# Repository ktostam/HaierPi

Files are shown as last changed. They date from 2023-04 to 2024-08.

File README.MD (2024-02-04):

# HaierPi



This project allows you to control HAIER heat pumps. 
## Tested with
1. AU082FYCRA(HW)
2. AU162FYCRA(HW)

All tests were performed on a pump with an additional ATW-a01 unit

However, it should work with all pumps that feature the YR-e27 remote control

If you have any question you can find me on discord:

[Discord Banner 2
](https://discord.gg/dVXmAfWt3P)

## Patrons
- Radek Michalowski

## Contributors
- @kocur on discord channel
- @Radek on discord channel

## Donation
If you like My work and want to support my work, you can:

[](https://patronite.pl/haierpi)

[](https://www.buymeacoffee.com/jacekbrzozZ)

Or if you from Poland:

[](https://buycoffee.to/jacekbrzozz)

## HARDWARE

## PCB
PCB layout is designed for both RaspberryPi zeroW and NanoPi neo 1.4.

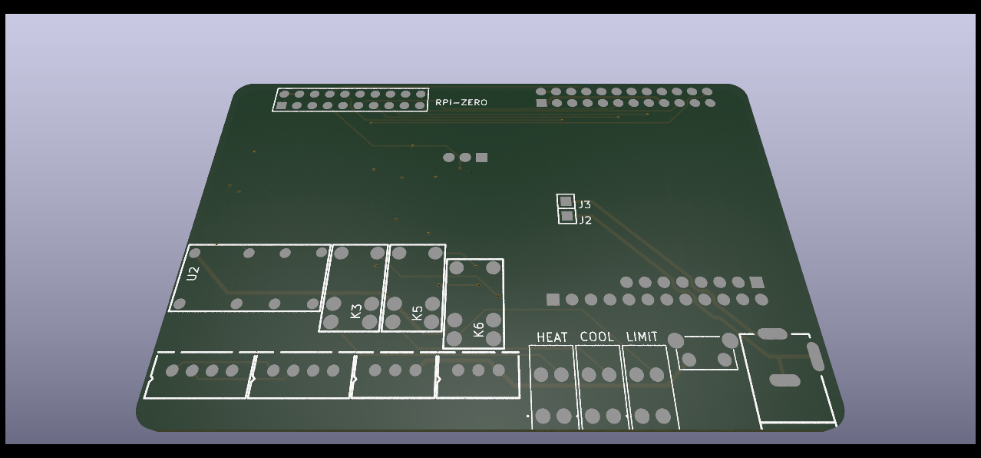
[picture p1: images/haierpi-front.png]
Front


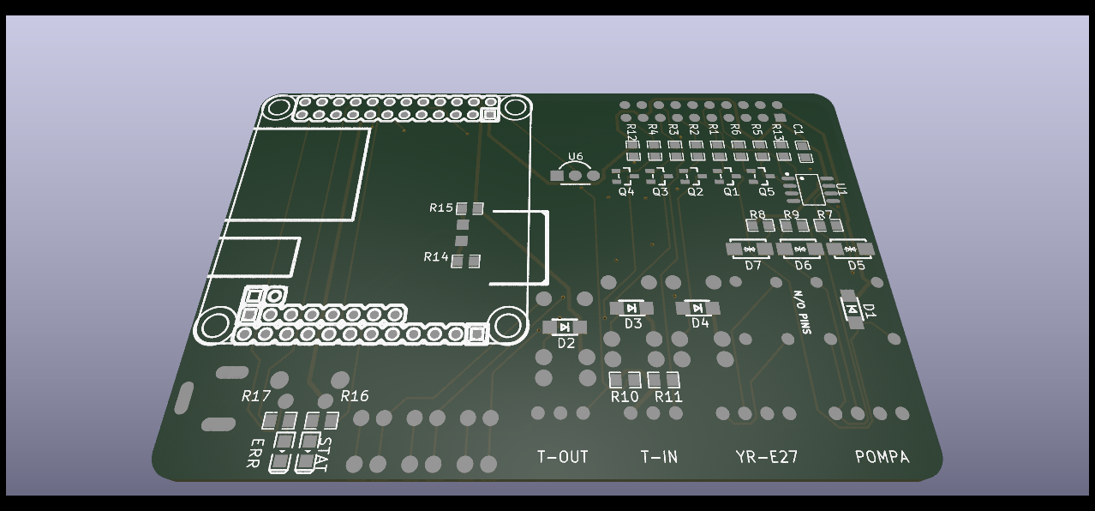
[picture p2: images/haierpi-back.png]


### PCB 1.1
The revised version of the PCB (1.1) no longer has mislabeling. In addition, one of the leds and the button is now also connected to the RPi.

In the future, HaierPi will support only NanoPi

### Component List

| Symbol | Value | Footprint |
|---|---|---|
| J1 | ADC-002 | ADC-002 |
| H3-H4 | JST XH 3 | JST-XH-TH-3-2.5  |
| POMPA,YR-E27  | JST XH 4 | JST-XH-TH-4-2.5  |
| CON1-CON3 | DG308-2.54/2 | |
| R1-R4 | 1K | SMD 0805 |
| R5-R8,R10-R12 | 4.7K | SMD 0805 |
| R9 | 120 | SMD 0805 |
| R13-R15 | 0 | SMD 0805 |
| R16-R17 | 330 | SMD 0805 |
| C1 | 104 | SMD 0805 |
| LED1 | RED | SMD 0805 |
| LED2 | GREEN | SMD 0805 |
| D1-D4 | 1N4007W | SOD-123 |
| D5-D7 | SMAJ12CA | DO214AC |
| REL1 | N4078-2C-5V-0.2W | N4078-2C-5V-0.2W |
| REL2-REL4 | HFD23-005-1ZS | HFD23-005-1ZS |
| U1 | MAX3485 | SOP-8 |

### ERRATA
In the first batch of PCB's was error
PCB descriptions of R1 and R2 are swapped places, so if you have that PCB,
you need to solder 1K resistor on R6 and 4.7 on R1

### Disclaimer
- R9 is RS485 EOL resistor. For this application don't solder it.
- Resistor R14-R15 is for choosing what type to board you want to connect (Raspberrypi/NanoPi Neo). For NanoPi, 
solder 0 Ohm resistor for powering NanoPi via GPIO. `If you connect Raspberry Pi don't solder it`, because powering RPi 
from GPIO bypasses builtin protections. I will be work but its not safe. If you connecting Raspberry Pi zero W, connect
`J2`(GND) to `PP6` pad, and `J3`(+5V) to `PP1` pad. 

### Raspberry Pi
if you want to use the script on the raspberry pi, you need to add the following settings to `config.txt`:

```shell
dtoverlay=w1-gpio,gpiopin=4
dtoverlay=pi3-disable-bt
enable_uart=1
```
Be aware that this settings will disable bluetooth. but we need use UART0

### Nano Pi neo 1.4
Script is also tested on NanoPi neo 1.4. For now no change is required, but in future, when support for hardware
temperature sensor will be added, we need to remap some GPIO pins. Further information will be added later.

### Other platform
script needs a relay to control the data flow in order to function properly, so best choice is some sort of SBC.
At the moment there are no plans to add support for other SBCs, but maybe in future I will add support for relays controlled by Home Assistant, 
so script may running on any platform, and only need a RS485 connection.

## Wiki
Now the documentation is on the wiki (only in polish for now)  [wiki](https://wiki.haos.it)

## Translation
- en
- pl
### if you want to help create a translation into another language write me an email or on the discord channel

## Version
### 1.37
- Add charts with some parameters
- DHW without limit function run in turbo mode
- Add estimated daily energy consumption, separate for central heating and domestic hot water

### 1.35
- Add MQTT Discovery (by Radek)
- Add more option for heatingcurve
- Add Anti ON-OFF function
- Add DHW without limit function
- Add Parameters page
- Add Temperature Charts
- Minor fixes

### 1.32
- Add parameters
- Add scheduler for CH and DHW
- Add translation to polish
- Now changes to settings do not require a restart of the service
- New update script, from now all new update dont need to manualy add option in config.ini.
- Minor fixes

### 1.31
- Add function for automatic/manual control of frequency limit relay
- Add function for automatic/manual control of mode quiet/eco/turbo
- IMPORTANT: new option added in config.ini. If you're updating
  from previous version you need to add options: `log_leve = ERROR` in  `[DEFAULT]` block in `config.ini`
  `flimit = manual`, `flimit_temp = 10`, `presetautochange = manual`,`presetquiet = 10`,`presetturbo = -10` in `[SETTINGS]` block in `config.ini`
- minor fixes
### 1.30
- Add possibility to change heating curve parameters via settings page.
- IMPORTANT: new option added in config.ini. If you're updating
  from previous version you need to add option `hcslope = 0.7`, `hcpshift = 1` and `hcamp = 1` in `[SETTINGS]` block in `config.ini`
- Add chart with heating curve visualisation.
- minor fixes

### 1.26
- IMPORTANT: new option added in config.ini. If you're updating
  from previous version you need to add option `firstrun = 0` in `[DEFAULT]` block in `config.ini`
- Setting page is kinda ready. (unfortunetly you need to manualy restart HaierPi service after saving change for now)
- Added new service for display HaierPi logs via web, for better debugging. Now you don't need to login via ssh
- Now script can talk with home assistant via MQTT (for now there is no mqtt autodiscovery, so you need to add yaml configuration manualy).
- Updates only send via mqtt if something is changes, not as before - everything every 10 seconds
- TODO: add option somewhere to restart HaierPi service. (e.g. after config.ini changed via web)
- Minor fixes

### 1.18
- Add ds18b20 sensor support as outside temp sensor.
- Fixed error handling that could cause sysexit.
- Adding new update mechanism
 need to add new option in `config.ini`:
```shell
    release=master
```
- Minor fixes
### 1.1
In this release I change library to control GPIO, Iam not using RPi.GPIO anymore, there is some issue with RPi.GPIO replacement for Nano Pi, so I decided to control GPIO via system /sys/class/gpio/. This is independent from used SBC,

in `config.ini` there is new configuration for PIN:
```shell
[GPIO]
modbus=17 #17 for raspberrypi, 0 for nanopi neo
freqlimit=27 #27 for raspberrypi, 2 for nanopi neo
heatdemand=22 #22 for raspberrypi, 3 for nanopi neo
cooldemand=10 #10 for raspberrypi, 64 for nanopi neo
```

### 1.0

First release. for now, the following features are available:

- Show pump parameters
- Set DHW temperature
- Set Central Heating Temperature 
- Heating water temperature is calculated according to the heating curve
- Online update

#### disclaimer:
In this release inside and outside temperature must be provided by Home Assistant sensors.
For future release hardware sensor will be supported (ds18b20 for outside and DHT22 for inside temperature).

In this release, MQTT support is not finished

## LICENSE
 GNU Affero General Public License v3 [©Jacek Brzozowski](https://github.com/ktostam/HaierPi)

In this project I'am using:
[open-meteo](https://open-meteo.com/) - CC BY 4.0

[jquery-schedule](https://github.com/Yehzuna/jquery-schedule) - MIT License

[sweetalert2](https://github.com/sweetalert2/sweetalert2) - MIT License

[bootstrap](https://github.com/twbs/bootstrap) - MIT License

[jquery](https://github.com/jquery/jquery) - MIT License

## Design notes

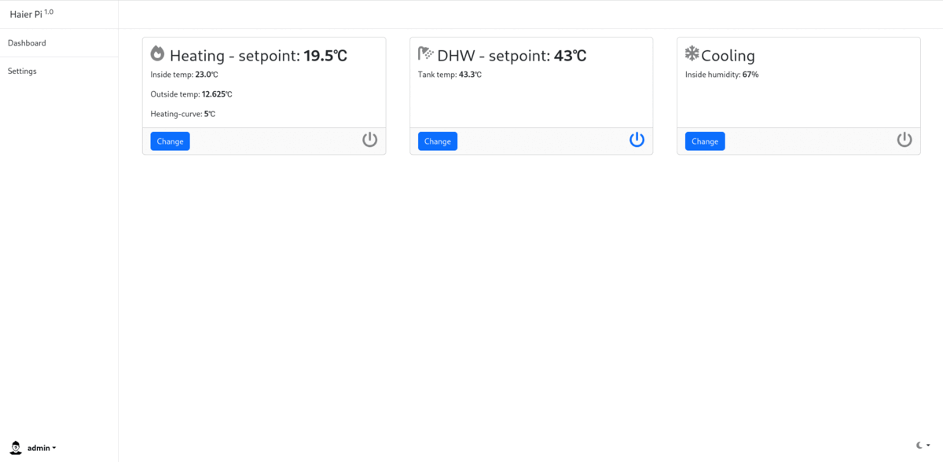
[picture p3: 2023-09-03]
images/screenshot.gif

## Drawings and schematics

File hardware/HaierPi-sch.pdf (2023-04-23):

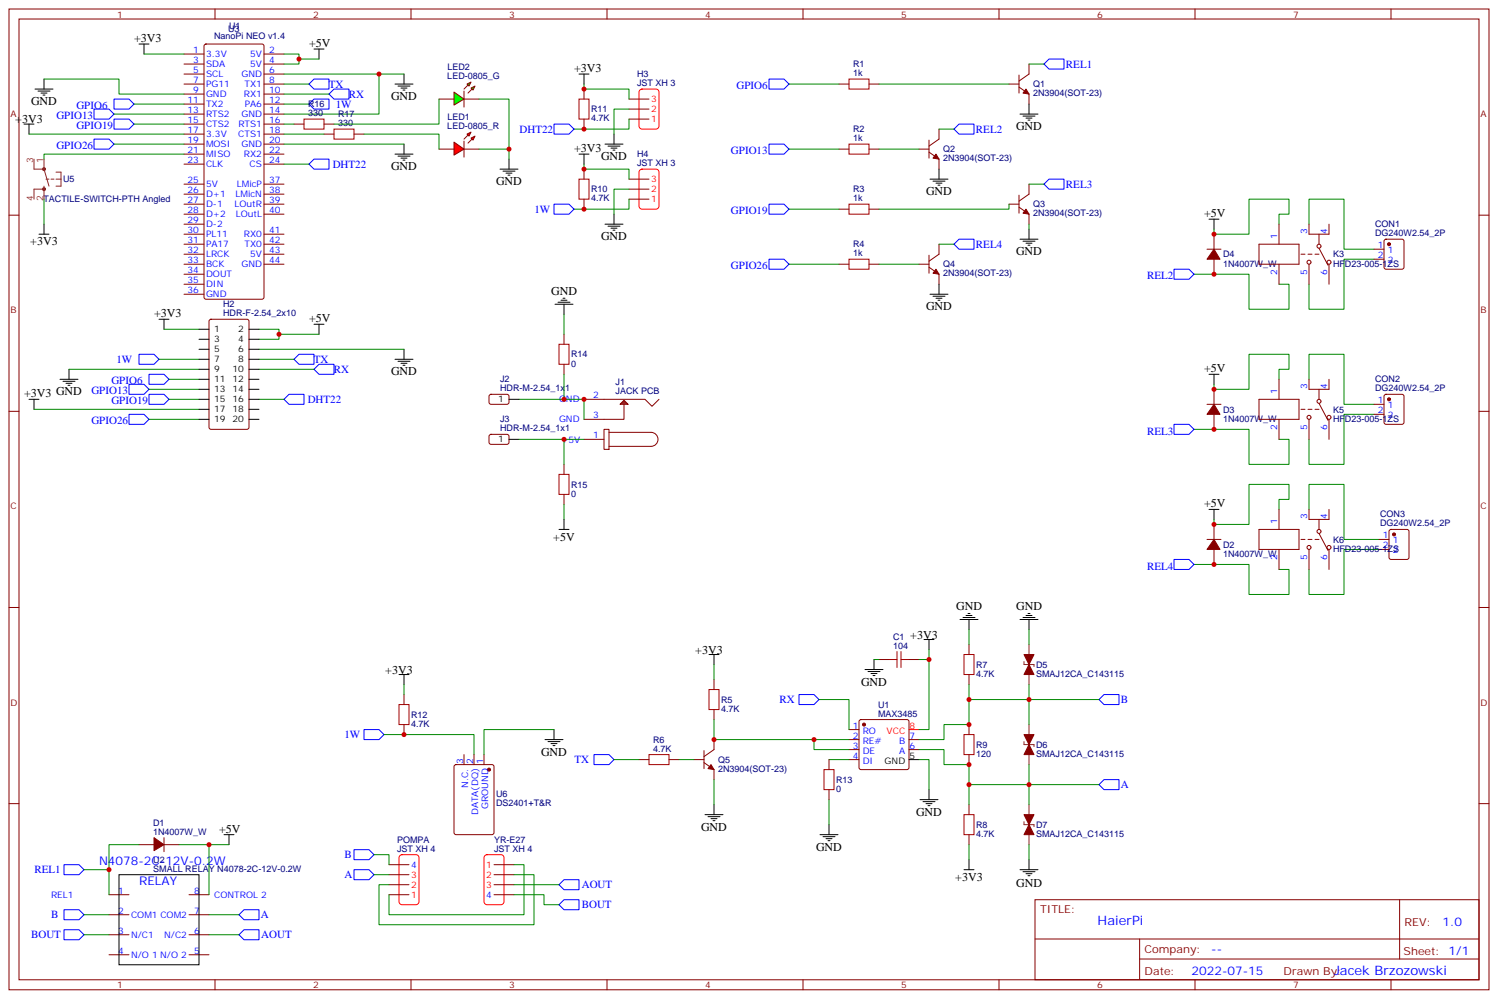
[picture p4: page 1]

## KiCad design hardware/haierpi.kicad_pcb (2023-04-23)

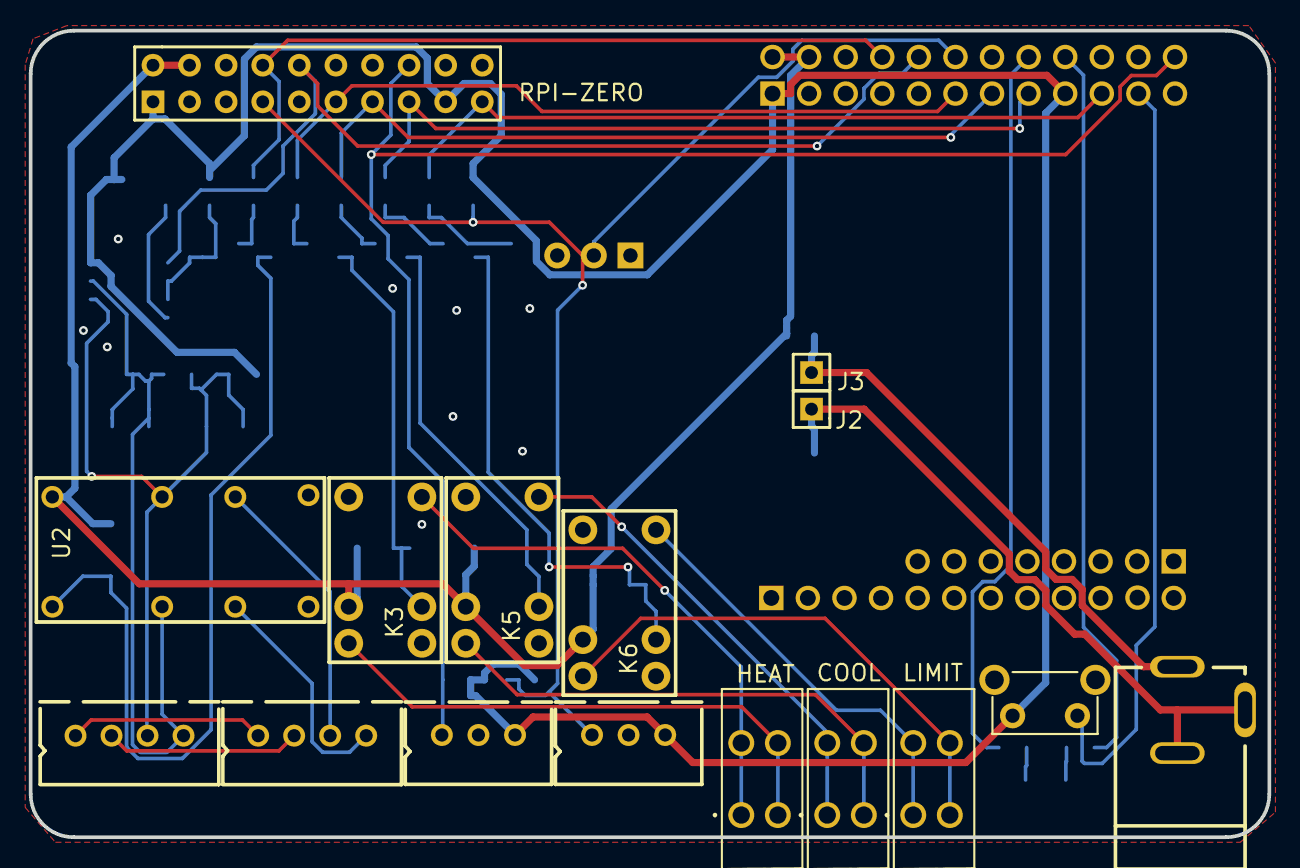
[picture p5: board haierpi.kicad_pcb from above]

Board: 2 copper layers, 86.0 x 56.0 mm, 51 parts (0 on the bottom side), 41 nets.

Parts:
C1: 104; C0805
COOL: DG240W2.54_2P; 2X2P_2.54X5
D1, D2, D3, D4: 1N4007W_W; SOD-123_L2.8-W1.8-LS3.7-RD
D5, D6, D7: SMAJ12CA_C143115; SMA_L4.4-W2.6-LS5.0-BI
ERR: LED-0805_R; LED0805_RED
HEAT: DG240W2.54_2P; 2X2P_2.54X5
J1: JACK PCB; ADC-002
J2, J3: HDR-M-2.54_1x1; HDR-M-2.54_1X1
K3, K5, K6: HFD23-005-1ZS; RELAY-TH_HFD23-005-1ZS
LIMIT: DG240W2.54_2P; 2X2P_2.54X5
POMPA: JST XH 4; JST-XH-TH-4-2.5
Q1, Q2, Q3, Q4, Q5: 2N3904(SOT-23); SOT-23-3_L2.9-W1.3-P1.90-LS2.4-TR
R1, R2, R3, R4: 1k; R0805
R5, R6, R7, R8, R10, R11, R12: 4.7K; R0805
R9: 120; R0805
R13, R14, R15: 0; R0805
R16, R17: 330; R0805
RPI-ZERO: HDR-F-2.54_2x10; HDR-F-2.54_2X10
STAT: LED-0805_G; LED0805_GREEN
T-IN: JST XH 3; JST-XH-TH-3-2.54
T-OUT: JST XH 3; JST-XH-TH-3-2.54
U1: MAX3485; SOP-8_L4.9-W3.9-P1.27-LS6.0-BL-1
U2: N/O PINS; SMALL N4078 DUAL COMS RELAY
U3: a; NANOPI_NEO_V1.4
U5: TACTILE-SWITCH-PTH Angled; SW_TACTILE_SPST_ANGLED
U6: DS2401+T&R; TO-92-3_L4.8-W3.7-P2.54-L
YR-E27: JST XH 4; JST-XH-TH-4-2.5

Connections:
1W: R10.1, R12.1, RPI-ZERO.7, T-OUT.1, U3.12, U6.2
+3V3: C1.2, R5.2, R8.1, R10.2, R11.2, R12.2, RPI-ZERO.1, RPI-ZERO.17, T-IN.3, T-OUT.3, U1.8, U3.1, U3.17, U5.2
+5V: D1.1, D2.1, D3.1, D4.1, K3.1, K5.1, K6.1, R15.1, RPI-ZERO.2, RPI-ZERO.4, U2.8, U3.2, U3.4
A: D6.1, D7.2, POMPA.3, R8.2, R9.1, U1.6, U2.7
AOUT: U2.6, YR-E27.3
B: D5.1, D6.2, POMPA.4, R7.1, R9.2, U1.7, U2.2
BOUT: U2.3, YR-E27.4
CON1_1: HEAT.1, K3.3
CON1_2: HEAT.2, K3.5
CON2_1: COOL.1, K5.3
CON2_2: COOL.2, K5.5
CON3_1: K6.3, LIMIT.1
CON3_2: K6.5, LIMIT.2
DHT22: R11.1, RPI-ZERO.16, T-IN.1, U3.24
GND: C1.1, D5.2, D7.1, ERR.2, Q1.1, Q2.1, Q3.1, Q4.1, Q5.1, R7.2, R13.1, R14.2, RPI-ZERO.6, RPI-ZERO.9, STAT.2, T-IN.2, T-OUT.2, U1.5, U3.6, U3.9, U3.14, U3.20, U6.1
GPIO6: R1.1, RPI-ZERO.11, U3.11
GPIO13: R2.1, RPI-ZERO.13, U3.13
GPIO19: R3.1, RPI-ZERO.15, U3.15
GPIO26: R4.1, RPI-ZERO.19, U3.19
J1_1: J1.1, J3.1, R15.2
J1_2: J1.2, J1.3, J2.1, R14.1
POMPA_1: POMPA.1, YR-E27.1
POMPA_2: POMPA.2, YR-E27.2
Q5_2: Q5.2, R6.1
R1_2: Q1.2, R1.2
R2_2: Q2.2, R2.2
R3_2: Q3.2, R3.2
R4_2: Q4.2, R4.2
R16_2: R16.2, STAT.1
R17_2: ERR.1, R17.2
REL1: D1.2, Q1.3, U2.1
REL2: D4.2, K3.2, Q2.3
REL3: D3.2, K5.2, Q3.3
REL4: D2.2, K6.2, Q4.3
RX: RPI-ZERO.10, U1.1, U3.10
TX: R6.2, RPI-ZERO.8, U3.8
U1_2: Q5.3, R5.1, U1.2, U1.3
U1_4: R13.2, U1.4
U3_16: R16.1, U3.16
U3_18: R17.1, U3.18
U5_1: U3.21, U5.1

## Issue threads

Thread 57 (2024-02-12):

Descriptions and typos

kamilostatek, 2024-02-12:
#: templates/index.html:331
msgid "Heating - setpoint: "
msgstr "Grzanie - zadana: "
in bubble (Inside setpoint temperature  / Temperatura zadana w domu)

#: templates/index.html:334
msgid "Heating-curve: "
msgstr "Krzywa grzewcza: "
in bubble (Temperature calculated from heating curve / Temperatura wyliczona z krzywej grzewczej)

#: templates/index.html:345
msgid "DHW - setpoint: "
msgstr "CWU - zadana: "
in bubble "Setpoint Tank temperature for Domestic Hot Water/ Zadana temperatura zbiornika CWU lub z wodą użytkową"

#: templates/index.html:374
msgid "Compressor Frequency limit: - "
msgstr "Ograniczenie częstotliwości sprężarki: - "
in bubble (Bypass/jumper on CN23 connector / Zworka na złączu CN23)

#: templates/index.html:389
msgid "Frequency limit temp: "
msgstr "Temperatura ograniczenia częstotliwości: "
in bubble (Temperature above which the function will be active / Temperatura powyżej której funkcja będzie aktywna)

#: templates/settings.html:259
msgid "Longitude"
msgstr "Długość geograficzna"

#: templates/settings.html:334
msgid "Heating DHW in Turbo mode and without freq.limit"
msgstr "Grzanie CWU w trybie Turbo i bez zworki ograniczenia częst."

#: templates/settings.html:335
msgid "When heating DHW turn off frequency limit relay and set Turbo mode"
msgstr ""
"Podczas grzania CWU zworka ograniczenia częstotliwości zostanie "
"wyłączona oraz zostanie włączony tryb Turbo"

#: templates/settings.html:385
msgid "Frequency limit"
msgstr "Ograniczenie częstotliwości sprężarki"

#: templates/settings.html:386 templates/settings.html:418
msgid "Automatic or manual frequency limit relay control"
msgstr ""
"Automatyczne lub ręczne sterowanie przekaźnikiem ograniczenia "
"częstotliwości"

New description for option:
Temperature Quiet mode
Temperatura trybu Quiet
W trybie automatycznym - temperatura powyżej której zostanie włączony tryb Quiet
In auto mode - temperature above which Queit mode will be active

Temperature Turbo mode
Temperatura trybu Turbo
W trybie automatycznym - temperatura powyżej której zostanie włączony tryb Turbo
In auto mode - temperature above which Turbo mode will be active

Descriptions for Parametres added in bubbles ?

1 Twi (temperature water input / temperatura wody dolotowej)
2 Two (temperature water output / temperatura wody wylotowej)
3 ΔT (the difference between Two and Twi / różnica pomiędzy Two i Twi)
4 Compressor fact (actual compressor frequency / aktualna częstotliwość sprężarki)
5 Compressor fset (set compressor frequency / zadana częstotliwość sprężarki)
6 Compressor current (prąd sprężarki)
7 Compressor voltage (napięcie sprężarki)
8 Compressor temp. (temperatura sprężarki)
9 Fan 1 speed (prędkość silnika wentylatora 1)
10 Fan 2 speed (prędkość silnika wentylatora 2)
11 Tao (temperatura otoczenia)
12 Td (temperatura strony tłocznej)
13 Ts (temperatura strony ssącej)
14 Thi (temperatura stanu ciekłego czynnika)
15 Tho (temperatura stanu gazowego czynnika)
14 Pd (ciśnienie strony tłocznej)
15 Ps (ciśnienie strony ssącej)
16 Pump (status pompy obiegowej)
17 3-way valve (zawór przełączający)
18 Daily CH kWh (zużycie CO w kWh)
19 Daily DHW kWh (zużycie CWU w kWh)
20 Total daily kWh (zużycie CO + CWU w kwh)

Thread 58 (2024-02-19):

parameter of termination of heating for fixed outside temperature value (high value when heating is not needed anymore)

petec999, 2024-02-19:
Parameter set in UI (e.g.) 17 degrees for outside temperature will cause stop of working of heat pump.
As heating for temperature is not needed when reached.
After temperature will gone down below that value (or another one - e.g. 15 degrees) heating procedure will be started. This solution is applicable in a sort of HPs and prevent power consumption when not needed. Sense of proposed solution to be considered, but it may cause building of a sort of dependencies related with that.

ktostam, 2024-02-19:
I can do something like this, but as an additional option disabled by default. This is an intentional action, if you turn off heating on the remote control and leave "Tank" alone, the 3-way valve will switch permanently to the tank position. This causes the tank to cool down faster (by gravity), unless you have a "heat trap" in the system

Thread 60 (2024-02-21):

adding logging time of archerror

petec999, 2024-02-21:
logging archerrors tagged with date, making it visible in ui

ktostam, 2024-02-21:
It is not that simple. Archerror do not have dates by themselves. the only thing I can do is during the occurrence of some error at a given time, I can save them somewhere along with the date. However, if the error occurs only for a very short moment I may not have time to catch the error, then the "archerror" will not be consistent with the dates it records.

In that case, archerror will display the errors even if they occurred for only a moment, and I will save all that occurred for more than a few seconds.

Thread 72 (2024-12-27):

saving 'heating-curve' value - pumps stops to work when 'inside temp' is unknown

petec999, 2024-12-27:
When value of 'inside temp' is unknown (e.g. it's provided by external sensor, or there's issue with reading value of haierpi sensor), pump stops to work as it cannot calculate 'heating-curve' value'. Proposed solution is to save and store last value and use it in case of such issue.

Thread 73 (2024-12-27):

relay limited frequency of compressor state is not going back after exiting of tank status when heating-curve value is entered manually

petec999, 2024-12-27:
Case: Pump is configured to use limited frequency of compressor using ui, heating-curve value as constant value is entered manually by ui, DHW scheduler is in use. When haierpi is going into 'DHW already off' state, heating curve is not recalculated (as value is entered manually) and pump is not going back into limited frequency of compressor state, TURBO state persists, what is not intended.

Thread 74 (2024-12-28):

Possibility of minor correction of the temperature displayed by the indoor and outdoor temperature sensor

kamilostatek, 2024-12-28:

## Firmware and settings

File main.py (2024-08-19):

from flask_simplelogin import SimpleLogin,is_logged_in,login_required, get_username
from werkzeug.security import check_password_hash, generate_password_hash
from schedule import every, run_pending, get_jobs, clear, cancel_job
from flask import Flask, flash, render_template, request, session, jsonify, redirect, Markup, send_file
from flask_babel import Babel, gettext
from pymodbus.client.sync import ModbusSerialClient
from werkzeug.utils import secure_filename
from w1thermsensor import W1ThermSensor
import collections
import paho.mqtt.client as mqtt
from termcolor import colored
from waitress import serve
from datetime import datetime
import HPi.GPIO as GPIO
import configparser
import subprocess
import threading
import requests
import logging
import PyHaier
import socket
import serial
import signal
import json
import time
import sys
import io

version="1.38"
ip_address=subprocess.run(['hostname', '-I'], check=True, capture_output=True, text=True).stdout.strip()
welcome="\n┌────────────────────────────────────────┐\n│              "+colored("!!!Warning!!!", "red", attrs=['bold','blink'])+colored("             │\n│      This script is experimental       │\n│                                        │\n│ Products are provided strictly \"as-is\" │\n│ without any other warranty or guaranty │\n│              of any kind.              │\n└────────────────────────────────────────┘\n","yellow", attrs=['bold'])
config = configparser.ConfigParser()
config.read('config.ini')
log_level_info = {'DEBUG': logging.DEBUG, 
                    'INFO': logging.INFO,
                    'WARNING': logging.WARNING,
                    'ERROR': logging.ERROR,
                    }

def loadconfig():
    logging.info("Loading new config.ini")
    global loglevel
    loglevel = config['MAIN']['log_level']
    global timeout
    timeout = config['MAIN']['heizfreq']
    global firstrun
    firstrun = config['MAIN']['firstrun']
    global bindaddr
    bindaddr = config['MAIN']['bindaddress']
    global bindport
    bindport = config['MAIN']['bindport']
    global modbusdev
    modbusdev = config['MAIN']['modbusdev']
    global release
    release = config['MAIN']['release']
    global expert_mode
    expert_mode = config['MAIN']['expert_mode']
    global settemp
    settemp = config['SETTINGS']['settemp']
    global slope
    slope = config['SETTINGS']['hcslope']
    global pshift
    pshift = config['SETTINGS']['hcpshift']
    global hcamp
    hcamp = config['SETTINGS']['hcamp']
    global heatingcurve
    heatingcurve = config['SETTINGS']['heatingcurve']
    global insidetemp
    insidetemp = config['SETTINGS']['insidetemp']
    global outsidetemp
    outsidetemp = config['SETTINGS']['outsidetemp']
    global omlat
    omlat = config['SETTINGS']['omlat']
    global omlon
    omlon = config['SETTINGS']['omlon']
    global humidity
    humidity = config['SETTINGS']['humidity']
    global flimit
    flimit = config['SETTINGS']['flimit']
    global flimittemp
    flimittemp = config['SETTINGS']['flimittemp']
    global presetautochange
    presetautochange = config['SETTINGS']['presetautochange']
    global presetquiet
    presetquiet = config['SETTINGS']['presetquiet']
    global presetturbo
    presetturbo = config['SETTINGS']['presetturbo']
    global antionoff
    antionoff = config['SETTINGS']['antionoff']
    global antionoffdelta
    antionoffdelta = config['SETTINGS']['antionoffdelta']
    global chscheduler
    chscheduler = config['SETTINGS']['chscheduler']
    global dhwscheduler
    dhwscheduler = config['SETTINGS']['dhwscheduler']
    global dhwwl
    dhwwl = config['SETTINGS']['dhwwl']
    global hcman
    hcman = config['SETTINGS']['hcman'].split(',')
    global use_mqtt
    use_mqtt = config['MQTT']['mqtt']
    global mqtt_broker_addr
    mqtt_broker_addr=config['MQTT']['address']
    global mqtt_broker_port
    mqtt_broker_port=config['MQTT']['port']
    global mqtt_ssl
    mqtt_ssl=config['MQTT']['mqtt_ssl']
    global mqtt_topic
    mqtt_topic=config['MQTT']['main_topic']
    global mqtt_username
    mqtt_username=config['MQTT']['username']
    global mqtt_password
    mqtt_password=config['MQTT']['password']
    global modbuspin
    modbuspin=config['GPIO']['modbus']
    global freqlimitpin
    freqlimitpin=config['GPIO']['freqlimit']
    global heatdemandpin
    heatdemandpin=config['GPIO']['heatdemand']
    global cooldemandpin
    cooldemandpin=config['GPIO']['cooldemand']
    global ha_mqtt_discovery
    ha_mqtt_discovery=config['HOMEASSISTANT']['ha_mqtt_discovery']
    global ha_mqtt_discovery_prefix
    ha_mqtt_discovery_prefix = config['HOMEASSISTANT']['ha_mqtt_discovery_prefix']

loadconfig()
newframe=""
writed=""
needrestart=0
dead=0

datechart=collections.deque(8640*[''], 8640)
tankchart=collections.deque(8640*[''], 8640)
twichart=collections.deque(8640*[''], 8640)
twochart=collections.deque(8640*[''], 8640)
tdchart=collections.deque(8640*[''], 8640)
tschart=collections.deque(8640*[''], 8640)
thichart=collections.deque(8640*[''], 8640)
thochart=collections.deque(8640*[''], 8640)
taochart=collections.deque(8640*[''], 8640)
pdchart=collections.deque(8640*[''], 8640)
pschart=collections.deque(8640*[''], 8640)
intempchart=collections.deque(8640*[''], 8640)
outtempchart=collections.deque(8640*[''], 8640)
humidchart=collections.deque(8640*[''], 8640)
hcurvechart=collections.deque(8640*[''], 8640)

modbus =  ModbusSerialClient(method = "rtu", port=modbusdev,stopbits=1, bytesize=8, parity='E', baudrate=9600)
ser = serial.Serial(port=modbusdev, baudrate = 9600, parity=serial.PARITY_EVEN,stopbits=serial.STOPBITS_ONE,bytesize=serial.EIGHTBITS,timeout=1)
app = Flask(__name__)
babel = Babel()
UPLOAD_FOLDER = '/opt/haier'
ALLOWED_EXTENSIONS = {'hpi'}
app.config['SECRET_KEY'] = '2bb80d537b1da3e38bd30361aa855686bde0eacd7162fef6a25fe97bf527a25b'
app.config['TEMPLATES_AUTO_RELOAD'] = True
app.config['UPLOAD_FOLDER'] = UPLOAD_FOLDER
set_log_level = log_level_info.get(loglevel, logging.ERROR)
logging.getLogger().setLevel(set_log_level)

#GPIO.setmode(GPIO.BCM) - no need anymore, script use own function independed from RPI.GPIO or NPi.GPIO
GPIO.setup(modbuspin, GPIO.OUT) #modbus
GPIO.setup(freqlimitpin, GPIO.OUT) #freq limit
GPIO.setup(heatdemandpin, GPIO.OUT) # heat demand
GPIO.setup(cooldemandpin, GPIO.OUT) # cool demand

statusmap=["intemp","outtemp","settemp","hcurve","dhw","tank","mode","humid","pch","pdhw","pcool", "theme", "tdts", "archerror", "compinfo", "fans", "tao", "twitwo", "thitho", "pump", "pdps", "threeway", "chkwhpd", "dhwkwhpd"]
mqtttop=["/intemp/state","/outtemp/state","/temperature/state","/heatcurve","/dhw/temperature/state","/dhw/curtemperature/state","/preset_mode/state","/humidity/state","/mode/state","/dhw/mode/state","/mode/state", "0", "/details/tdts/state","/details/archerror/state","/details/compinfo/state","/details/fans/state","/details/tao/state","/details/twitwo/state","/details/thitho/state","/details/pump/state","/details/pdps/state","/details/threeway/state","/details/chkwhpd/state", "/details/dhwkwhpd"]
status=['N.A.','N.A.',settemp,'N.A.','N.A.','N.A.','N.A.','N.A.','N.A.','N.A.','N.A.', 'light', 'N.A.','N.A.','N.A.','N.A.','N.A.','N.A.','N.A.','N.A.','N.A.','N.A.', '0', '0']
R101=[0,0,0,0,0,0]
R141=[0,0,0,0,0,0,0,0,0,0,0,0,0,0,0,0]
R201=[0]
R241=[0,0,0,0,0,0,0,0,0,0,0,0,0,0,0,0,0,0,0,0,0,0]
twicheck=[0,0]

def get_locale():
    return request.accept_languages.best_match(['en', 'pl'])

def allowed_file(filename):
    return '.' in filename and \
           filename.rsplit('.', 1)[1].lower() in ALLOWED_EXTENSIONS

def handler(signum, frame):
    print(colored("\rCtrl-C - Closing... please wait, this can take a while.", 'red', attrs=["bold"]))
    GPIO.cleanup(modbuspin)
    GPIO.cleanup(freqlimitpin)
    GPIO.cleanup(heatdemandpin)
    GPIO.cleanup(cooldemandpin)
    ser.reset_input_buffer()
    ser.reset_output_buffer()
    ser.close()
    if use_mqtt == '1':
        client.publish(mqtt_topic + "/connected","offline", qos=1, retain=True)
        client.disconnect()
    event.set()
    clear()
    exit(1)

def is_raspberrypi():
    try:
        with io.open('/sys/firmware/devicetree/base/model', 'r') as m:
            if 'raspberry pi' in m.read().lower(): return True
    except Exception: pass
    return False

def isfloat(num):
    try:
        float(num)
        return True
    except ValueError:
        return False

def check_my_users(user):
    my_users = json.load(open("users.json"))
    if not my_users.get(user["username"]):
        return False
    stored_password = my_users[user["username"]]["password"]
    if check_password_hash(stored_password, user["password"]):
        return True
    return False
simple_login = SimpleLogin(app, login_checker=check_my_users)

def gpiocontrol(control, value):
    if control == "modbus":
        if value == "1":
            GPIO.output(modbuspin, GPIO.HIGH)
        elif value == "0":
            GPIO.output(modbuspin, GPIO.LOW)
    if control == "heatdemand":
        if value == "1":
            GPIO.output(heatdemandpin, GPIO.HIGH)
        if value == "0":
            GPIO.output(heatdemandpin, GPIO.LOW)
    if control == "cooldemand":
        if value == "1":
            GPIO.output(cooldemandpin, GPIO.HIGH)
        if value == "0":
            GPIO.output(cooldemandpin, GPIO.LOW)
    if control == "freqlimit":
        if value == "1":
            GPIO.output(freqlimitpin, GPIO.HIGH)
        if value == "0":
            GPIO.output(freqlimitpin, GPIO.LOW)

def WritePump():
    global newframe
    global writed
    comm=1
    if newframe:
        logging.info(newframe)
        newframelen=len(newframe)
        while (comm):
            rs = ser.read(1).hex()
            if rs == "032c":
                for ind in range(22):
                    ser.read(2).hex()
            comm=0
            gpiocontrol("modbus", "1")

        if newframelen == 6:
            logging.info("101")
            time.sleep(1)
            modbus.connect()
            modbusresult=modbus.write_registers(101, newframe, unit=17)
            modbus.close()
            gpiocontrol("modbus","0")
            logging.info(modbusresult)
            writed="1"
            # if hasattr(modbusresult, 'fcode'):
            #     if modbusresult.fcode < 0x80:
            #         print(modbusresult.fcode)
            #         writed="1"
            #     else:
            #         writed="2"
        elif newframelen == 16:
            logging.info("141")
        elif newframelen == 1:
            logging.info("201")
            time.sleep(1)
            modbus.connect()
            modbusresult=modbus.write_registers(201, newframe, unit=17)
            modbus.close()
            gpiocontrol("modbus","0")
            logging.info(modbusresult)
            writed="1"
        newframe=""

def ReadPump():
    global R101
    global R141
    global R201
    global R241
    global newframe
    time.sleep(0.2)
    while (1):
        if (ser.isOpen() == False):
            logging.warning(colored("Closed serial connection.", 'red', attrs=["bold"]))
            break
        if event.is_set():
            break
        if newframe:
            WritePump()
        try:
            rs = ser.read(1).hex()
            if rs == "11":
                rs = ser.read(2).hex()
                # # zapisy
                # if rs == "1000":
                #     rs = ser.read(8).hex()
                #     bits = str(rs)[-2:]
                #     rsa = ser.read(int(bits, 16)).hex()
                #     head = "111000"
                #     toprinttmp = head + rs + rsa
                #     toprint = " ".join(toprinttmp[i:i + 2] for i in range(0, len(toprinttmp), 2))
                #     print(toprint)
                #     # zapisy end
                if rs == "030c":
                    R101 = []
                    D101 = []
                    for ind in range(6):
                        rs = ser.read(2).hex()
                        if rs:
                            R101.append(int(rs, 16))
                            m, l = divmod(int(rs, 16), 256)
                            D101.append(m)
                            D101.append(l)
                    logging.debug(D101)
                if rs == "0320":
                    R141 = []
                    D141 = []
                    for ind in range(16):
                        rs = ser.read(2).hex()
                        if rs:
                            R141.append(int(rs, 16))
                            m, l = divmod(int(rs, 16), 256)
                            D141.append(m)
                            D141.append(l)
                    logging.debug(D141)
                if rs == "0302":
                    R201 = []
                    for ind in range(1):
                        rs = ser.read(2).hex()
                        if rs:
                            R201.append(int(rs, 16))
                    logging.debug(R201)
                if rs == "032c":
                    R241 = []
                    D241 = []
                    for ind in range(22):
                        rs = ser.read(2).hex()
                        if rs:
                            R241.append(int(rs, 16))
                            m, l = divmod(int(rs, 16), 256)
                            D241.append(m)
                            D241.append(l)
                    logging.debug(D241)
        except:
            break

def on_connect(client, userdata, flags, rc):
    logging.info(colored("MQTT - Connected", "green", attrs=['bold']))
    client.subscribe(mqtt_topic + '/#')
    client.publish(mqtt_topic + "/connected","online", qos=1, retain=True)
    if ha_mqtt_discovery == "1":
        client.subscribe(ha_mqtt_discovery_prefix+"/status")
        client.subscribe("hass/status")
        configure_ha_mqtt_discovery()


def on_disconnect(client, userdata, rc):  # The callback for when
    logging.warning(colored("Disconnected from MQTT with code: {0}".format(str(rc)), 'red', attrs=['bold']))

def on_message(client, userdata, msg):  # The callback for when a PUBLISH 
    #message is received from the server. 
    #print("Message received-> " + msg.topic + " " + str(msg.payload))  # Print a received msg
    if msg.topic == mqtt_topic + "/power/set":
        logging.info("New power state from mqtt:")
        client.publish(mqtt_topic + "/power/state",msg.payload.decode('utf-8'), qos=1, retain=True)
    elif msg.topic == mqtt_topic + "/preset_mode/set":
        logging.info("New preset mode")
        payload=str(msg.payload.decode('utf-8')).lower()
        if payload == 'quiet' or payload == 'eco' or payload == 'turbo':
            try:
                presetchange(payload)
            except:
                logging.error("MQTT: cannot set new preset: "+payload)
        else:
                logging.error("MQTT: cannot set new preset: "+payload)
    elif msg.topic == mqtt_topic + "/flimit/set":
        logging.info("Frequency limit")
        try:
            flimitchange(str(msg.payload.decode('utf-8')))
        except:
            logging.error("MQTT: cannot set flimit relay")
    elif msg.topic == mqtt_topic + "/mode/set":
        logging.info("New mode")
        newmode=msg.payload.decode('utf-8')
        if newmode == "heat":
            try:
                statechange("pch", "on", "1")
                client.publish(mqtt_topic + "/mode/state",newmode, qos=1, retain=True)
            except:
                logging.error("MQTT: cannot set mode")
        elif newmode == "cool":
            try:
                statechange("pcool", "on", "1")
                client.publish(mqtt_topic + "/mode/state",newmode, qos=1, retain=True)
            except:
                logging.error("MQTT: cannot set mode")
        elif newmode == "off":
            try:
                statechange("pump", "off", "1")
                client.publish(mqtt_topic + "/mode/state",newmode, qos=1, retain=True)
            except:
                logging.error("MQTT: cannot set mode")
        else:
            logging.error("MQTT: mode unsupported")

    elif msg.topic == mqtt_topic + "/temperature/set":
        try:
            tempchange("heat",format(float(msg.payload)),"2")
            client.publish(mqtt_topic + "/temperature/state",str(float(msg.payload)), qos=1, retain=True)
        except:
            logging.error("MQTT: New temp error: payload - "+format(float(msg.payload)))
    elif msg.topic == mqtt_topic + "/dhw/mode/set":
        logging.info("New mode")
        payload=msg.payload.decode('utf-8')
        if payload == "heat":
            newmode="on"
        else:
            newmode=payload
        try:
            statechange("pdhw", str(newmode), "1")
            client.publish(mqtt_topic + "/dhw/mode/state", str(payload), qos=1, retain=True)
        except:
            logging.error("MQTT: cannot change DHW mode - payload:"+str(newmode))
    elif msg.topic == mqtt_topic + "/dhw/temperature/set":
        logging.info("New temperature")
        newtemp=int(float(msg.payload.decode('utf-8')))
        try:
            tempchange("dhw", str(newtemp), "2")
            client.publish(mqtt_topic + "/dhw/temperature/state", str(newtemp), qos=1, retain=True)
        except:
            logging.error("MQTT: cannot change DHW temperature - payload:"+str(newtemp))
    elif msg.topic == ha_mqtt_discovery_prefix + "/status" or msg.topic == "hass/status":
        if ha_mqtt_discovery == "1":
            logging.info(msg.topic + " | " + msg.payload.decode('utf-8'))
            if msg.payload.decode('utf-8').strip() == "online":
                logging.info("Home Assistant online")
                configure_ha_mqtt_discovery()
    
def tempchange(which, value, curve):
    global R101
    global newframe
    global writed
    if curve == "1":
        if which == "heat":
            logging.info("Central heating: "+str(value))
            for a in range(3):
                if len(R101) == 6:
                    chframe = PyHaier.SetCHTemp(R101, float(value))
                    continue
            if chframe.__class__ == list:
                newframe=chframe
                return "OK"
            else:
                logging.error("ERROR: Cannot set new CH temp")
                msg=gettext("ERROR: Cannot set new CH temp")
                return msg
        elif which == "dhw":
            logging.info("Domestic Hot Water: "+value)
            dhwframe = PyHaier.SetDHWTemp(R101, int(value))
            if dhwframe.__class__ == list:
                newframe=dhwframe
                msgt=gettext("Domestic Hot Water ")
            else:
                logging.error(gettext("Error: Cannot set new DHW temp"))
                msg=gettext("ERROR: Cannot set new temp")
                state="error"
                return jsonify(msg=msg, state=state)

        for i in range(50):
            logging.info(writed)
            if writed=="1":
                msg=msgt+gettext(" temperature changed!")
                state="success"
                writed="0"
                break
            elif writed=="2":
                msg=gettext("Modbus communication error.")
                state="error"
                writed="0"
            else:
                msg=gettext("Modbus connection timeout.")
                state="error"
                writed="0"
            time.sleep(0.2)
    elif curve == "0":
        if which == "heat":
            status[statusmap.index("settemp")] = float(value)
            config['SETTINGS']['settemp'] = str(value)    # update
            with open('config.ini', 'w') as configfile:    # save
                config.write(configfile)
            if use_mqtt == "1":
                client.publish(mqtt_topic + "/temperature/state",str(value), qos=1, retain=True)
                if ha_mqtt_discovery=="1":
                    Settemp_number.set_value(float(value))
            msg = gettext("Central Heating temperature changed!")
            state = "success"
    elif curve == "2":
        if which == "heat":
            status[statusmap.index("settemp")] = float(value)
            config['SETTINGS']['settemp'] = str(value)
            with open('config.ini', 'w') as configfile:
                config.write(configfile)
            return "OK"
        elif which == "dhw":
            logging.info(gettext("Domestic Hot Water: ")+value)
            dhwframe = PyHaier.SetDHWTemp(R101, int(value))
            if dhwframe.__class__ == list:
                newframe=dhwframe
                return "OK"
            else:
                logging.error("Error: Cannot set new DHW temp")
                return "ERROR"

    return jsonify(msg=msg, state=state)

def presetchange(mode):
    with app.app_context():
        global newframe
        try:
            newframe=PyHaier.SetMode(mode)
            if use_mqtt == "1":
                client.publish(mqtt_topic + "/preset_mode/state", str(mode), qos=1, retain=False)
            #msg=gettext("New preset mode: ")+str(mode)
            msg="New preset mode: "+str(mode)
            state="success"
            return jsonify(msg=msg, state=state)
        except:
            if use_mqtt == "1":
                client.publish(mqtt_topic + "/preset_mode/state", "none", qos=1, retain=False)
            #msg=gettext("Preset mode not changed")
            msg="Preset mode not changed"
            state="error"
            return jsonify(msg=msg, state=state)
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

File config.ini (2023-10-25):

[DEFAULT]
# on which port the program will listen (for ports below 1024 you need root permision)
bindport = 4000

# on witch IP address program will listen
#  use 127.0.0.1 for localhost only (not visible in network)
#  use 0.0.0.0 for bind all available IP addresses
bindaddress = 0.0.0.0

# provide device name for RS485 adapter.
#  If you use builtin serial port on raspberry pi use /dev/AMA0.
#   You also need to chance some settings in /boot/config.txt
#   This settings change maping for serial ports, it will disable bluetooth adapter,
#   so if you need bluetooth for something, just use USB RS485 adapter.
# If you use NanoPi Neo use /dev/ttyS1 as serial port, and in /boot/dietpiEnv.txt add 'uart1' in line overlays=
modbusdev = /dev/ttyAMA0

# how often in seconds heating curve will be calculated. No need to be more than 10 minutes (600s)
heizfreq = 10

# From what branch you want to download updates:
# master - should be stable release.
# test - release for testing new features
# dev - only if you have python knowlage and want to develop by yourself
# defaul relase=master
release=master

# If script is run first time, this value is 1
firstrun = 1

# Default log level, you can set ERROR,WARNING,INFO,DEBUG
log_level = ERROR

[SETTINGS]
# desired room temperature
settemp = 20

# heating curve can be defined as:
#  auto - for using buildin alghoritm (depend both on external and internal temp)
#  1-5 - choose one of predefined static heating curve (depend only on external temp)
#  manual - use your own static curve for preset temperature thresholds (-20℃ - 20℃ with 5℃  step)
heatingcurve = auto

# option for "auto" heating curve:
# slope, parallel shift and amplification.
hcslope = 0.7
hcpshift = 1
hcamp = 1

# frequency of heating curve calculation (in minutes)
heizfreq = 10

# Change of frequency limit
# manual - manual changing
# auto - change depending on outside temperature
flimit = manual

# In auto mode temperature above which the relay will be switched on
flimittemp = 10

# Change of preset
# manual - manual changing
# auto - change depending on outside temperature
presetautochange = auto

# In auto mode temperature above which the quiet mode will be switched on
presetquiet = 10
# In auto mode temperature below which the turbo mode will be switched on
presetturbo = -10

# insidetemp,outsidetemp and humidity can be set to:
#  builtin - for using sensor connected to PCB
#  ha - for read sensor from Home Assistant api
insidetemp = ha
outsidetemp = ha
humidity = ha

[HOMEASSISTANT]
HAADDR = 127.0.0.1
HAPORT = 8123
KEY = Home Assistenet HA
insidesensor = sensor.temperature_in
outsidesensor = sensor.temperature_out
humiditysensor = sensor.humidity

[MQTT]
mqtt = 0
address = 127.0.0.1
port = 1883
main_topic = climate/haier
username = mqtt
password = password

[GPIO]
#17 for raspberrypi, 0 for nanopi neo
modbus=17
#27 for raspberrypi, 2 for nanopi neo
freqlimit=27
#22 for raspberrypi, 3 for nanopi neo
heatdemand=22
#10 for raspberrypi, 64 for nanopi neo
cooldemand=10

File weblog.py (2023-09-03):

from flask import Flask, render_template, Response
import subprocess

app = Flask(__name__)

def stream_journal_entries():
    # Execute the journalctl command with the '-f' flag to follow new entries
    proc = subprocess.Popen(['journalctl', '-f', '-t', 'HaierPi', '-p','info'], stdout=subprocess.PIPE, stderr=subprocess.STDOUT, universal_newlines=True)

    # Read and yield each line of the journal output
    for line in iter(proc.stdout.readline, ''):
        yield 'data: {}\n\n'.format(line.strip())

@app.route('/')
def index():
    return render_template('weblog.html')

@app.route('/stream')
def stream():
    return Response(stream_journal_entries(), mimetype='text/event-stream', headers={"Access-Control-Allow-Origin": "*"} )

if __name__ == '__main__':
    app.run(host="0.0.0.0")

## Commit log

2023-04-18 first version
    [config.txt]
2023-04-23 work in progress update
    [config.txt]
2023-05-05 add reading from DS18b20 sensor connected directly to pcb.
2023-05-13 fix update.py script, now installation requirements is in virtual env
    [update.py]
2023-05-14 fix CH temp change
    [main.py]
2023-05-23 Fix problem with tunning off everythin when turning off DHW.
    [main.py]
2023-05-29 Add support for reading local DHT22 sensor, unfortunately python has troubles with reading dht22, so I need to use external C binary
2023-06-10 fix in calcdewpoint function
    [main.py]
2023-06-10 Disable change button for cooling (for now only option is calculating dew point)
2023-10-19 initial change - not working
    [main.py]
2023-10-24 fix for R241 register
    [main.py]
2023-10-25 not available outtemp can couse error with curvecalc function.
    [main.py]
2023-10-29 - now PyHaier is required in 0.2.8 version - add webpage with parameters (not all is correct right now). - Rename DEFAULT section to MAIN in config.ini (required for automatic update script) - from n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
    [config.ini, main.py, update.py]
2023-11-02 Add AntiON-OFF function Add DHW without limit function Add Central Heating and Domestic Hot Water scheduler. Few minor fixes.
    [config.ini, main.py, update.py]
2023-12-03 dhw without limit fix, change DEFAULT to MAIN in settings template
    [main.py]
2023-12-08 rename dht22 bin for nanopi add dht22 bin for raspberrypi determine is running on RaspberryPi or Nano and use propper binary for dht22
2023-12-18 - New way of calculating automatic heating curve - Static curve based on slope - Manual heating curve - Possibility of direct control of water temperature - Expert mode (pump can set CH temp from 20C)
2023-12-18 add crashlog function generating dump from journal into crashlog file when any of threads is dead
    [main.py]
2023-12-19 small fix in curvecalc
    [main.py]
2023-12-26 curvecalc fix in manual mode
    [main.py]
2023-12-28 add backup configuration, minor fixes
    [main.py]
2023-12-31 Estimate daily energy ussage of central heating and domestic hot water
2024-01-02 fix crash problem when wrong preset is set via mqtt
    [main.py]
2024-07-29 Update main.py
    small bug
    [main.py]

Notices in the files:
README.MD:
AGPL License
